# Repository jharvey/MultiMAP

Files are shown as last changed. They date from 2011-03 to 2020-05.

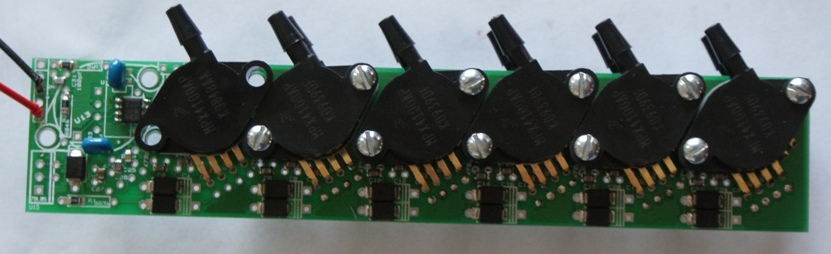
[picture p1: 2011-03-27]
pictures/2010-05-29 001.JPG

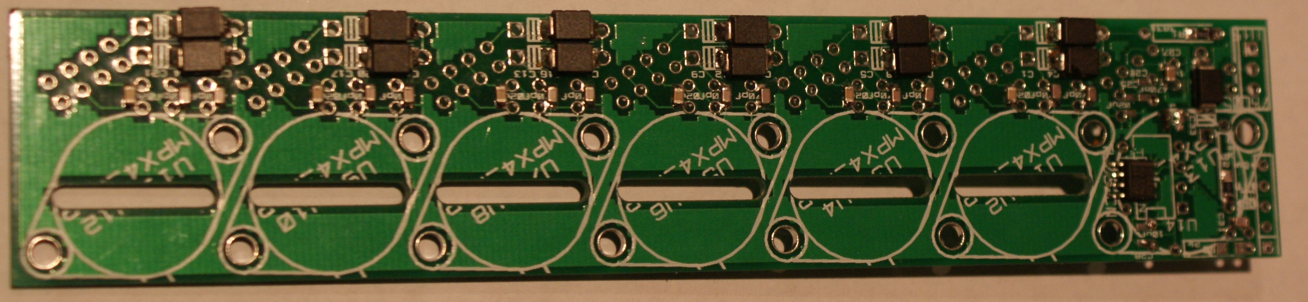
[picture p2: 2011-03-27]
pictures/other/2010-04-24 001.JPG

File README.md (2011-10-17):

### MultiMAP

This is a circuit board that would most typically be used for automotive engines running ITB setups. This board will combine multiple MAP signals, and report the lowest MAP signal to the engine control computer. This project includes designs for 2,4,6,8 and 12 MAP signals. 

This project includes, Gerber MFG files that can be uploaded to almost any MFG house, such that PCB's can be obtained. It includes BOM's and simulation files, as well as the KICAD PCB layout files. 

I have also uploaded files to BatchPCB, such that if someone want's the board, they can simply go there and purchase it.

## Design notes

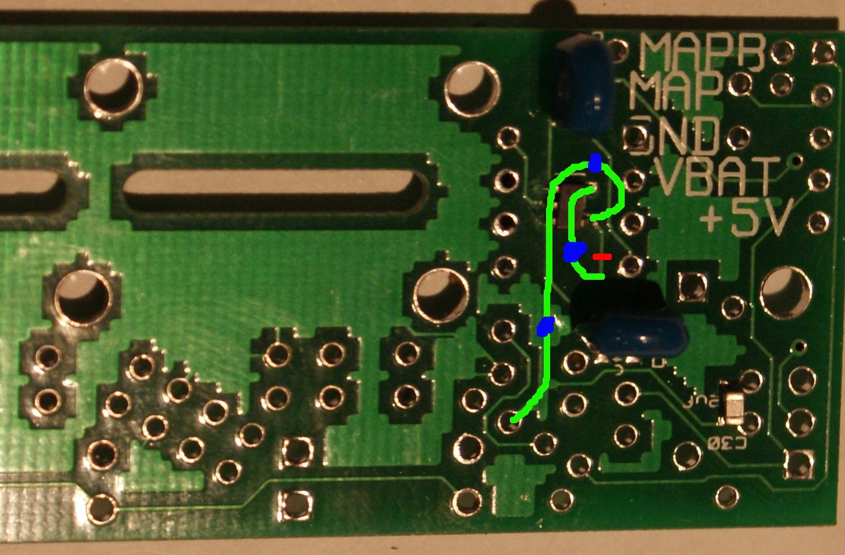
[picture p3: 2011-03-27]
pictures/other/back_mod.JPG

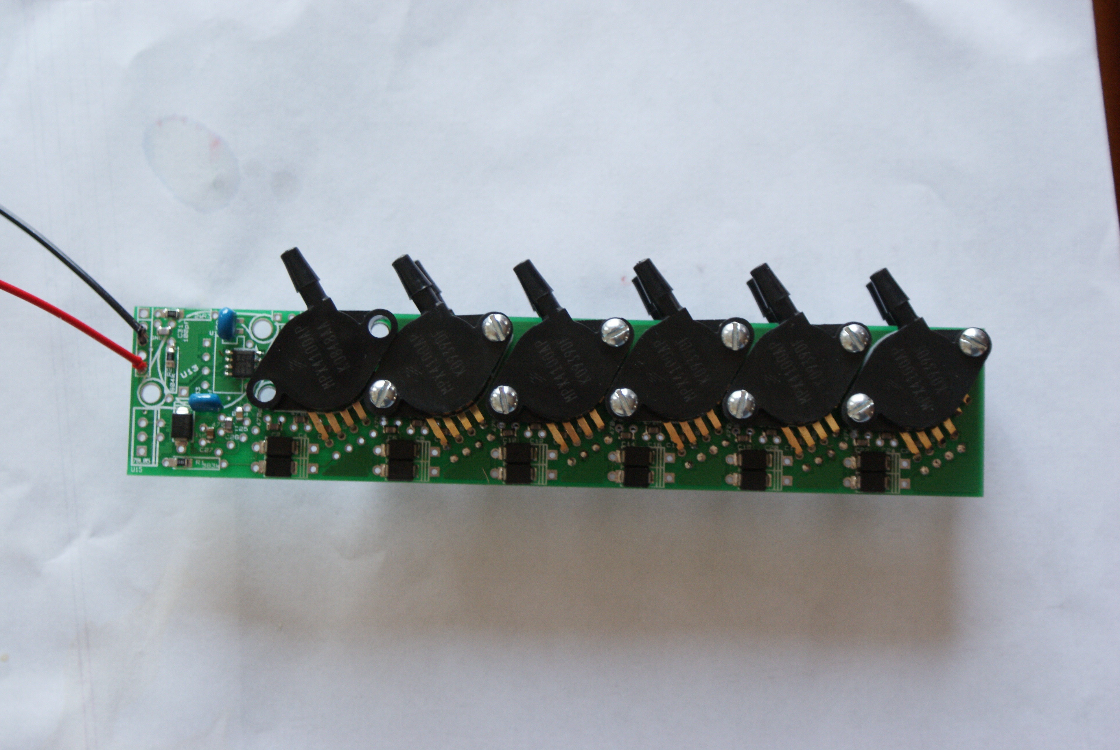
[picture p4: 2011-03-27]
pictures/2010-05-29 001small.JPG

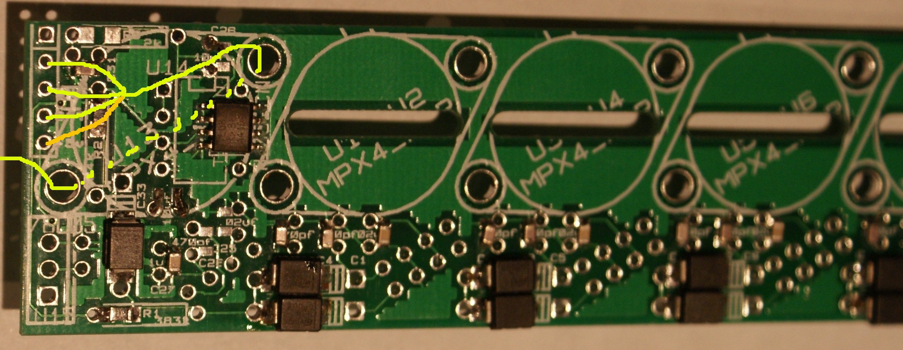
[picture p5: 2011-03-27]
pictures/other/wire_strain-relief.JPG

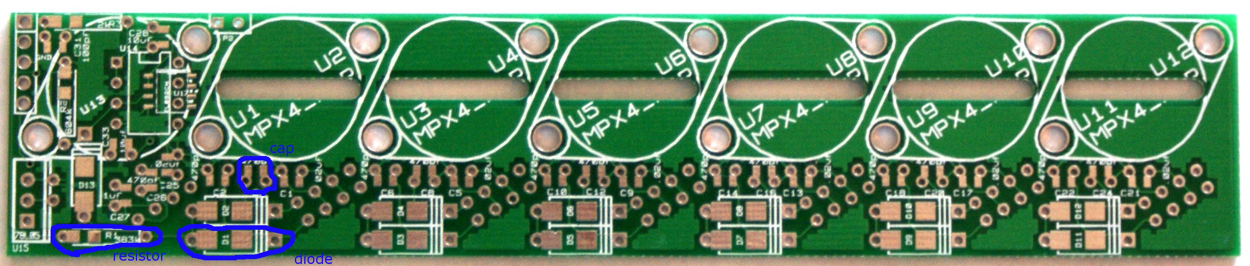
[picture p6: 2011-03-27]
pictures/other/footprints-modules.JPG

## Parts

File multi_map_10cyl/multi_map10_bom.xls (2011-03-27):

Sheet: processed_data
ref | value | MFG |  | Vendor 1 |  | Vendor 2 | # | $
C31 | 100pf | avx | 08055A101JAT2A | quest | 08055A101JAT2A | mouser | 581-08055A101J | $0.110 | These parts are always required, and this list shows surface mount devices only.
C1 | .02uf | avx | 08055C202KAT2A | quest | 08055C202KAT2A | mouser | 581-08055C202K | $0.130
C5 | .02uf | avx | 08055C202KAT2A | quest | 08055C202KAT2A | mouser | 581-08055C202K | $0.130
C9 | .02uf | avx | 08055C202KAT2A | quest | 08055C202KAT2A | mouser | 581-08055C202K | $0.130
C13 | .02uf | avx | 08055C202KAT2A | quest | 08055C202KAT2A | mouser | 581-08055C202K | $0.130
C17 | .02uf | avx | 08055C202KAT2A | quest | 08055C202KAT2A | mouser | 581-08055C202K | $0.130
C30 | 22uf | avx | 08056D226MAT2A | quest | 08056D226MAT2A | mouser | 581-08056D226M | $1.000
R3 | 2k | Vishay | CRCW08052K00FKTA | quest | CRCW08052K00FKTA | mouser | 71-CRCW08052001FT | $0.050
R1 | 383k | Vishay | CRCW0805383KFKTA | quest | CRCW0805383KFKTA | mouser | 71-CRCW0805-383K | $0.040
R2 | 604k | vishay | CRCW0805604KFKTA | quest | CRCW0805604KFKTA | mouser | 71-CRCW0805-604K-E3 | $0.050
D1 | DIODE | stmicro | STPS340U | quest | STPS340U | mouser | 511-STPS340U | $0.524
D2 | DIODE | stmicro | STPS340U | quest | STPS340U | mouser | 511-STPS340U | $0.524
D3 | DIODE | stmicro | STPS340U | quest | STPS340U | mouser | 511-STPS340U | $0.524
D4 | DIODE | stmicro | STPS340U | quest | STPS340U | mouser | 511-STPS340U | $0.524
D5 | DIODE | stmicro | STPS340U | quest | STPS340U | mouser | 511-STPS340U | $0.524
D6 | DIODE | stmicro | STPS340U | quest | STPS340U | mouser | 511-STPS340U | $0.524
D7 | DIODE | stmicro | STPS340U | quest | STPS340U | mouser | 511-STPS340U | $0.524
D8 | DIODE | stmicro | STPS340U | quest | STPS340U | mouser | 511-STPS340U | $0.524
D9 | DIODE | stmicro | STPS340U | quest | STPS340U | mouser | 511-STPS340U | $0.524
D10 | DIODE | stmicro | STPS340U | quest | STPS340U | mouser | 511-STPS340U | $0.524
D13 | DIODE | stmicro | STPS340U | quest | STPS340U | mouser | 511-STPS340U | $0.524
U14 | TL082CN | TI | TL082IDR | quest | TL082IDR | mouser | 595-TL082QDRQ1 | $0.760
C2 | 470pf | Vishay | VJ0805A471JXAAT | quest | VJ0805A471JXAAT | mouser | 581-08051A471J | $0.150
C4 | 470pf | Vishay | VJ0805A471JXAAT | quest | VJ0805A471JXAAT | mouser | 581-08051A471J | $0.150
C6 | 470pf | Vishay | VJ0805A471JXAAT | quest | VJ0805A471JXAAT | mouser | 581-08051A471J | $0.150
C8 | 470pf | Vishay | VJ0805A471JXAAT | quest | VJ0805A471JXAAT | mouser | 581-08051A471J | $0.150
C10 | 470pf | Vishay | VJ0805A471JXAAT | quest | VJ0805A471JXAAT | mouser | 581-08051A471J | $0.150
C12 | 470pf | Vishay | VJ0805A471JXAAT | quest | VJ0805A471JXAAT | mouser | 581-08051A471J | $0.150
C14 | 470pf | Vishay | VJ0805A471JXAAT | quest | VJ0805A471JXAAT | mouser | 581-08051A471J | $0.150
C16 | 470pf | Vishay | VJ0805A471JXAAT | quest | VJ0805A471JXAAT | mouser | 581-08051A471J | $0.150
C18 | 470pf | Vishay | VJ0805A471JXAAT | quest | VJ0805A471JXAAT | mouser | 581-08051A471J | $0.150
C20 | 470pf | Vishay | VJ0805A471JXAAT | quest | VJ0805A471JXAAT | mouser | 581-08051A471J | $0.150
 | PCB |  |  | Batch PCB |  |  |  | $27.190
U1 | MPX4_MAP | freescale | MPX4100AP | digikey | MPX4100AP-ND | mouser | 841-MPX4100AP1 | $11.970 | This is the non boosted MAP sensor, If your system is boosted, change to the MPX4???
U2 | MPX4_MAP | freescale | MPX4100AP | digikey | MPX4100AP-ND | mouser | 841-MPX4100AP5 | $11.970
U3 | MPX4_MAP | freescale | MPX4100AP | digikey | MPX4100AP-ND | mouser | 841-MPX4100AP6 | $11.970
U4 | MPX4_MAP | freescale | MPX4100AP | digikey | MPX4100AP-ND | mouser | 841-MPX4100AP7 | $11.970
U5 | MPX4_MAP | freescale | MPX4100AP | digikey | MPX4100AP-ND | mouser | 841-MPX4100AP8 | $11.970
U6 | MPX4_MAP | freescale | MPX4100AP | digikey | MPX4100AP-ND | mouser | 841-MPX4100AP9 | $11.970
U7 | MPX4_MAP | freescale | MPX4100AP | digikey | MPX4100AP-ND | mouser | 841-MPX4100AP10 | $11.970
U8 | MPX4_MAP | freescale | MPX4100AP | digikey | MPX4100AP-ND | mouser | 841-MPX4100AP11 | $11.970
U9 | MPX4_MAP | freescale | MPX4100AP | digikey | MPX4100AP-ND | mouser | 841-MPX4100AP12 | $11.970
U10 | MPX4_MAP | freescale | MPX4100AP | digikey | MPX4100AP-ND | mouser | 841-MPX4100AP2 | $11.970
C27 | 1uf | avx | 08053D105KAT2A | quest | 08053D105KAT2A | mouser | 581-08053D105K | $0.660 | If you choose to provide 12V to the baord instead of 5V, added these parts.
U15 | 78L05 | on-semi | MC7805ACTG | newark | 45J1442 |  |  |  | Most ECU MAP's will provide 5V instead of 12V.
U16 | MAX1682 | Maxim | MAX1682EUK-T | summit | MAX1682EUK+T |  |  |  | Most setups will need the onboard 10v generator, to include this option, add these parts
C28 | 10uf | avx | 08052G106ZAT2A | quest | 08052G106ZAT2A |  |  | $0.130 | (supplying 12V still requires these parts if the 10V generation is desired)
C33 | 10uf | avx | 08052G106ZAT2A | quest | 08052G106ZAT2A |  |  | $0.130
 |  |  |  |  |  |  |  |  | If you decide to go without the onbaord 10V generator, do not include C28, C33 or U16, instead
 |  |  |  |  |  |  |  |  | add a jumper wire in the P2 socket and change R1 and R2 to these resistors.
 |  |  |  |  |  |  |  |  | The below parts are not typically populated
U13 | MPX4_MAP |  |  |  |  |  |  |  | U13 is for barametric correct, which isn't needed with the above suggested MAP sensor.
C29 | #NAME? |  |  |  |  |  |  |  | C29 and C32 allow some adjustment to the 10V generator if required.
C32 | #NAME?
P1 | CONN_5 |  |  |  |  |  |  |  | This is the connector where the wires are soldered to this board,
U? | TL082CN |  |  |  |  |  |  |  | This is the second foot print for the opamp. It allows both SMT and thru hole components.
 |  |  |  |  |  |  | total cost | $157.73

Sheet: multi_map_raw_data
ref | value | sheet number | sheet name | footprint | Field1 | Field2
C1 | .02uf | SM0805-C1 | avx | 08055C202KAT2A | quest | 08055C202KAT2A
C10 | 470pf | SM0805-C1 | Vishay | VJ0805A471JXAAT | quest | VJ0805A471JXAAT
C12 | 470pf | SM0805-C1 | Vishay | VJ0805A471JXAAT | quest | VJ0805A471JXAAT
C13 | .02uf | SM0805-C1 | avx | 08055C202KAT2A | quest | 08055C202KAT2A
C14 | 470pf | SM0805-C1 | Vishay | VJ0805A471JXAAT | quest | VJ0805A471JXAAT
C16 | 470pf | SM0805-C1 | Vishay | VJ0805A471JXAAT | quest | VJ0805A471JXAAT
C17 | .02uf | SM0805-C1 | avx | 08055C202KAT2A | quest | 08055C202KAT2A
C18 | 470pf | SM0805-C1 | Vishay | VJ0805A471JXAAT | quest | VJ0805A471JXAAT
C2 | 470pf | SM0805-C1 | Vishay | VJ0805A471JXAAT | quest | VJ0805A471JXAAT
C20 | 470pf | SM0805-C1 | Vishay | VJ0805A471JXAAT | quest | VJ0805A471JXAAT
C21 | .02uf | SM0805-C1 | avx | 08055C202KAT2A | quest | 08055C202KAT2A
C22 | 470pf | SM0805-C1 | Vishay | VJ0805A471JXAAT | quest | VJ0805A471JXAAT
C24 | 470pf | SM0805-C1 | Vishay | VJ0805A471JXAAT | quest | VJ0805A471JXAAT
C25 | .02uf | SM0805-C1 | avx | 08055C202KAT2A | quest | 08055C202KAT2A
C26 | 470pf | SM0805-C1 | Vishay | VJ0805A471JXAAT | quest | VJ0805A471JXAAT
C27 | 1uf | SM0805-C1 | avx | 08053D105KAT2A | quest | 08053D105KAT2A
C28 | 10uf | SM0805-C1 | mutara | GRM40C0G202J050AL | quest | GRM40C0G202J050AL
C29 | #NAME? | SM0805-C1
C30 | 22uf | SM0805-C1 | avx | 08056D226MAT2A | quest | 08056D226MAT2A
C31 | 100pf | SM0805-C1 | avx | 08055A101JAT2A | quest | 08055A101JAT2A
C32 | #NAME? | SM0805-C1
C33 | 10uf | SM0805-C1 | mutara | GRM40C0G202J050AL | quest | GRM40C0G202J050AL
C4 | 470pf | SM0805-C1 | Vishay | VJ0805A471JXAAT | quest | VJ0805A471JXAAT
C5 | .02uf | SM0805-C1 | avx | 08055C202KAT2A | quest | 08055C202KAT2A
C6 | 470pf | SM0805-C1 | Vishay | VJ0805A471JXAAT | quest | VJ0805A471JXAAT
C8 | 470pf | SM0805-C1 | Vishay | VJ0805A471JXAAT | quest | VJ0805A471JXAAT
C9 | .02uf | SM0805-C1 | avx | 08055C202KAT2A | quest | 08055C202KAT2A
D1 | DIODE | D4-SMB | stmicro | STPS340U | quest | STPS340U
D10 | DIODE | D4-SMB | stmicro | STPS340U | quest | STPS340U
D11 | DIODE | D4-SMB | stmicro | STPS340U | quest | STPS340U
D12 | DIODE | D4-SMB | stmicro | STPS340U | quest | STPS340U
D13 | DIODE | D4-SMB | stmicro | STPS340U | quest | STPS340U
D2 | DIODE | D4-SMB | stmicro | STPS340U | quest | STPS340U
D3 | DIODE | D4-SMB | stmicro | STPS340U | quest | STPS340U
D4 | DIODE | D4-SMB | stmicro | STPS340U | quest | STPS340U
D5 | DIODE | D4-SMB | stmicro | STPS340U | quest | STPS340U
D6 | DIODE | D4-SMB | stmicro | STPS340U | quest | STPS340U
D7 | DIODE | D4-SMB | stmicro | STPS340U | quest | STPS340U
D8 | DIODE | D4-SMB | stmicro | STPS340U | quest | STPS340U
D9 | DIODE | D4-SMB | stmicro | STPS340U | quest | STPS340U
P1 | CONN_5 | SIL-5
R1 | 383k | R4-SM0805 | Vishay | CRCW0805383KFKTA | quest | CRCW0805383KFKTA
R2 | 604k | R4-SM0805 | vishay | CRCW0805604KFKTA | quest | CRCW0805604KFKTA
R3 | 2k | R4-SM0805 | Vishay | CRCW0805100RFKEA | quest | CRCW0805100RFKEA
U1 | MPX4_MAP | MPX-4_MAP_2
U10 | MPX4_MAP | MPX-4_MAP
U11 | MPX4_MAP | MPX-4_MAP_2
U12 | MPX4_MAP | MPX-4_MAP
U13 | MPX4_MAP | MPX-4_MAP_2
U14 | TL082CN | 8DIP300 | TI | TL082IDR | quest | TL082IDR
U15 | 78L05 | TO220_VERT | on-semi | MC7805ACTG | newark | 45J1442
U16 | MAX1682 | SOT23-5 | Maxim | MAX1682EUK-T | summit | MAX1682EUK+T
U2 | MPX4_MAP | MPX-4_MAP
U3 | MPX4_MAP | MPX-4_MAP_2
U4 | MPX4_MAP | MPX-4_MAP
U5 | MPX4_MAP | MPX-4_MAP_2
U6 | MPX4_MAP | MPX-4_MAP
U7 | MPX4_MAP | MPX-4_MAP_2
U8 | MPX4_MAP | MPX-4_MAP
U9 | MPX4_MAP | MPX-4_MAP_2
U? | TL082CN | SO8E

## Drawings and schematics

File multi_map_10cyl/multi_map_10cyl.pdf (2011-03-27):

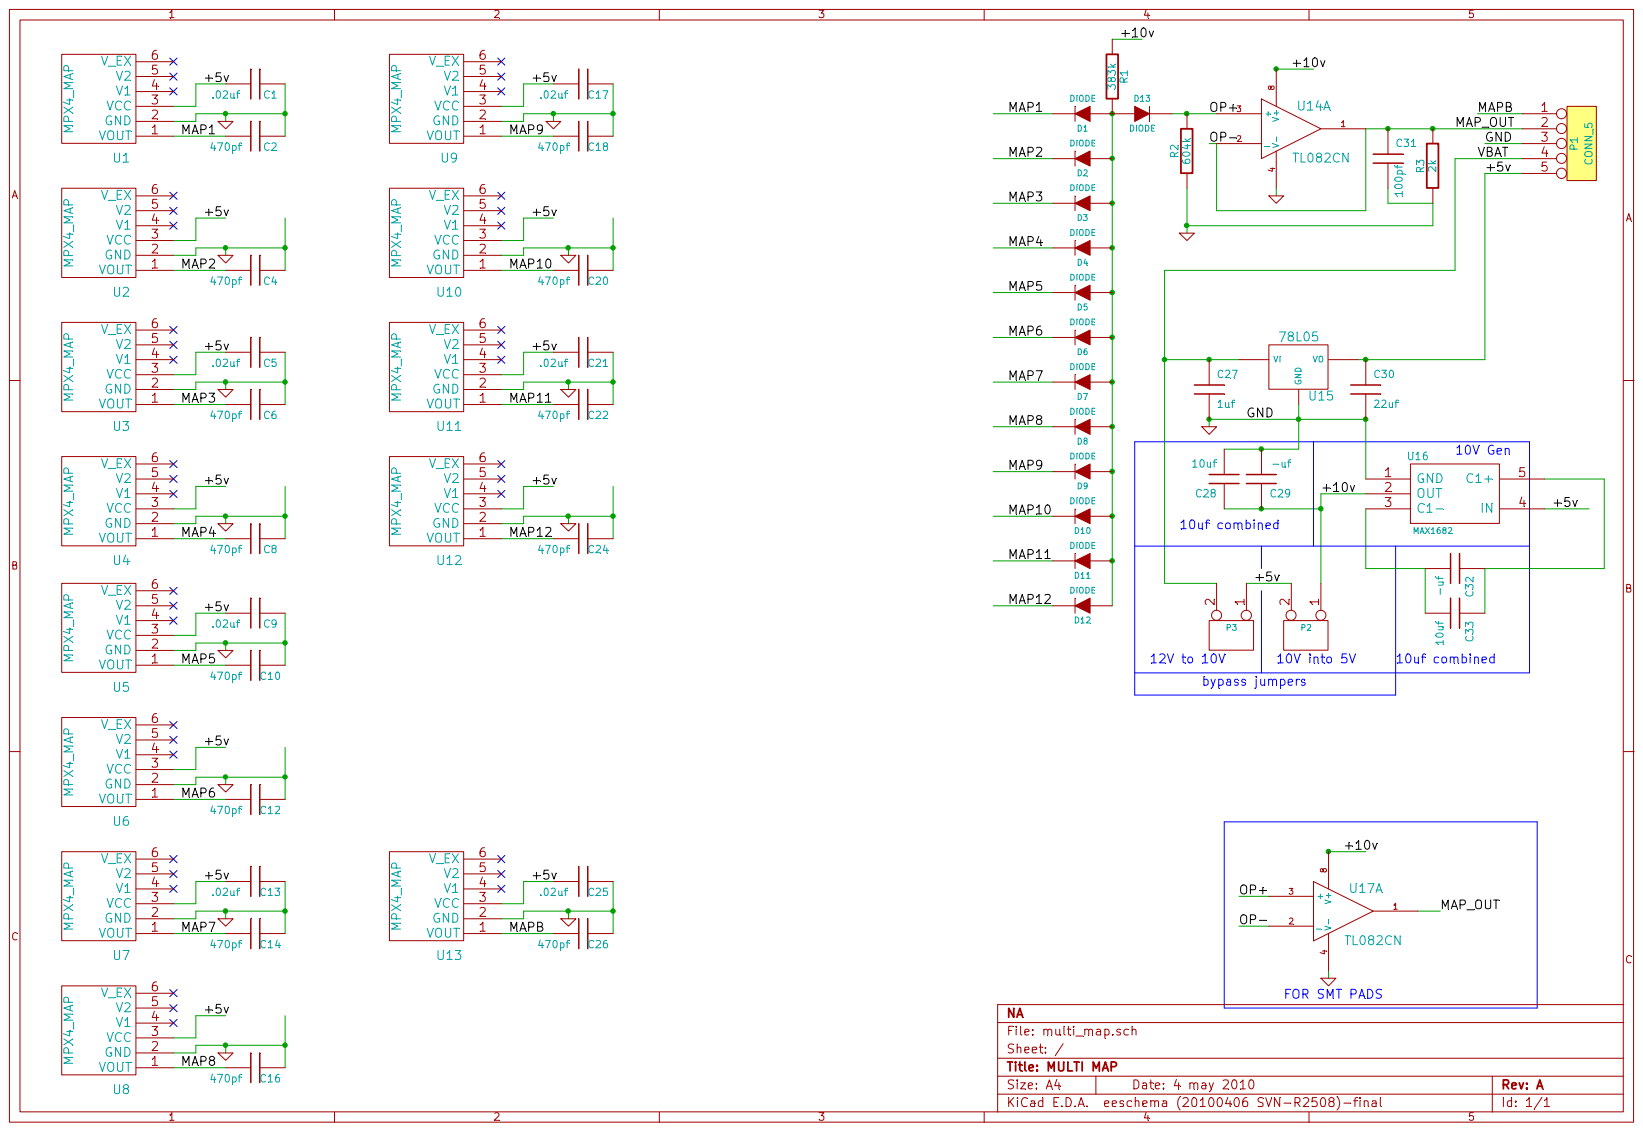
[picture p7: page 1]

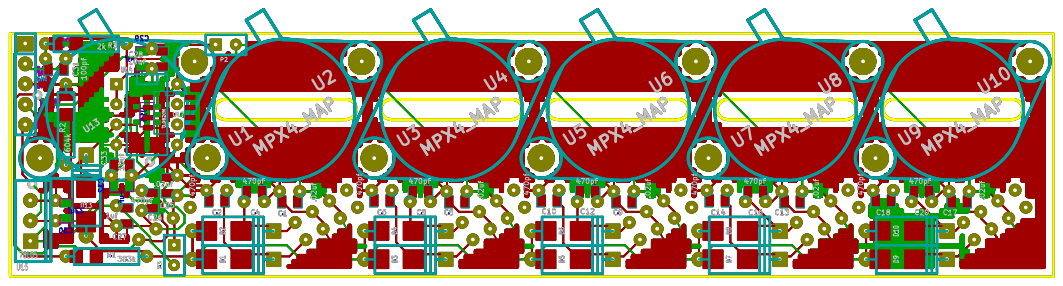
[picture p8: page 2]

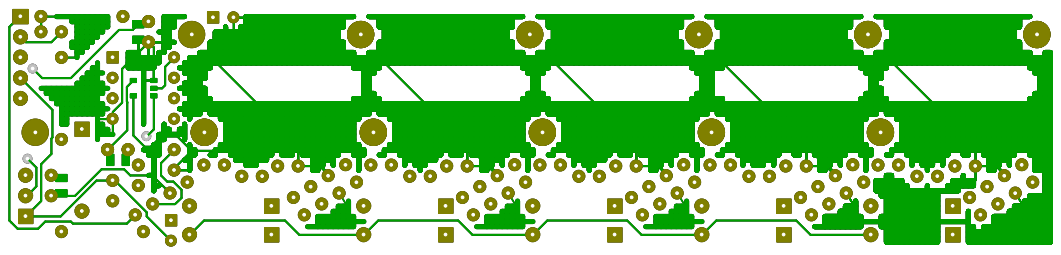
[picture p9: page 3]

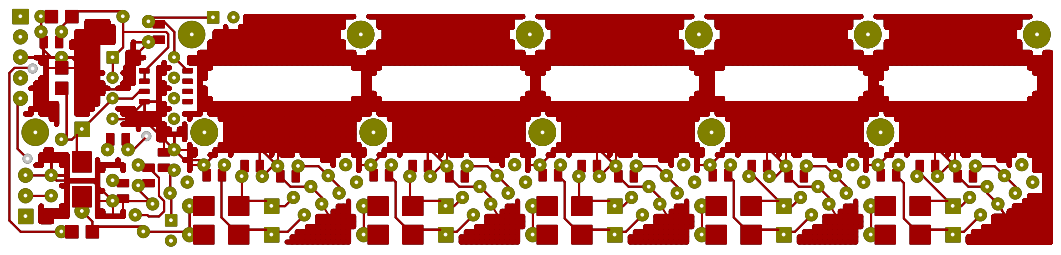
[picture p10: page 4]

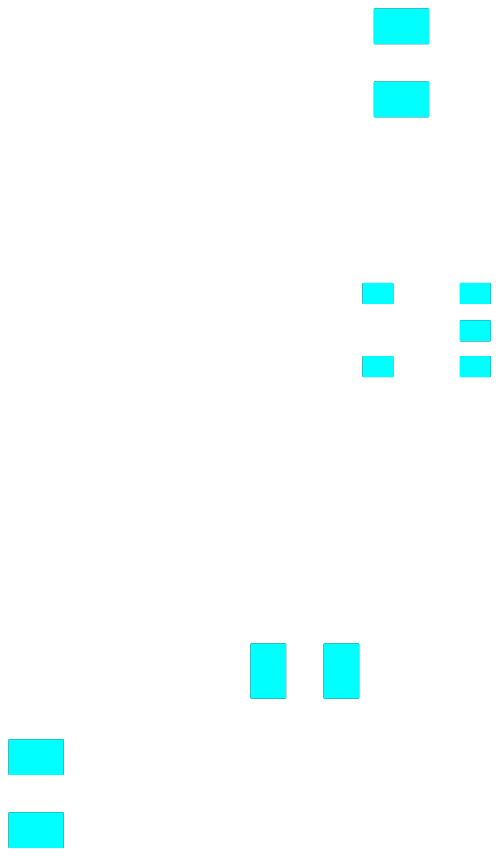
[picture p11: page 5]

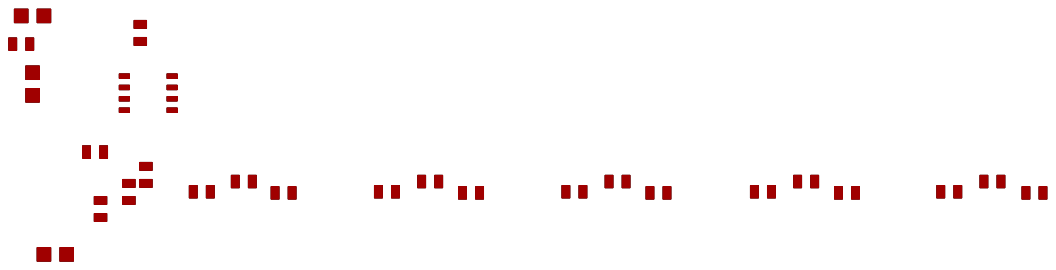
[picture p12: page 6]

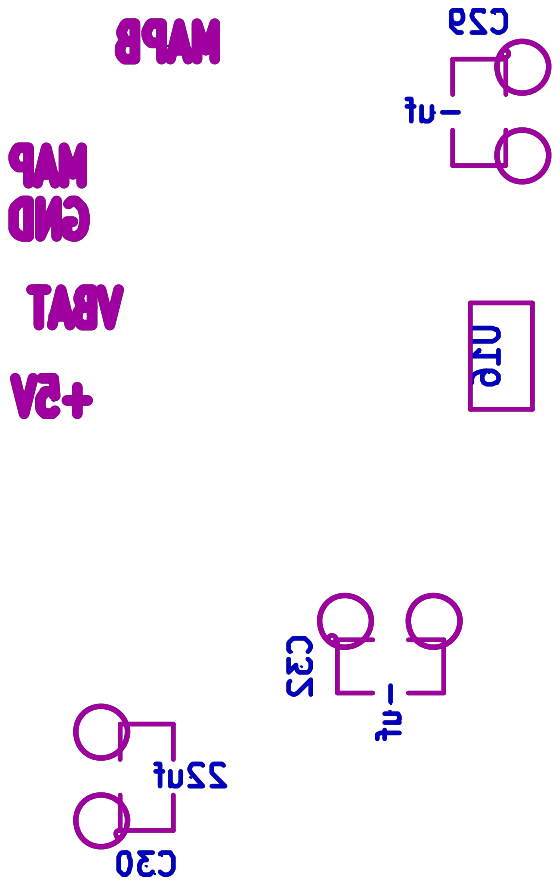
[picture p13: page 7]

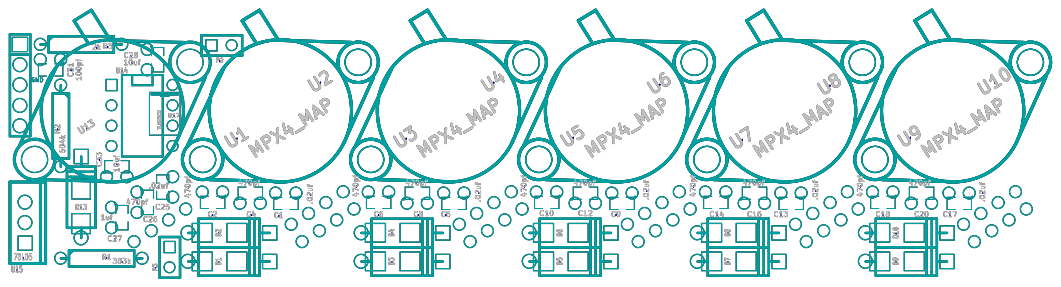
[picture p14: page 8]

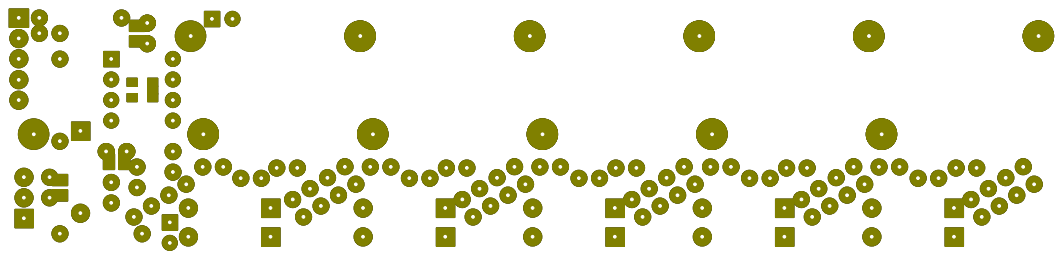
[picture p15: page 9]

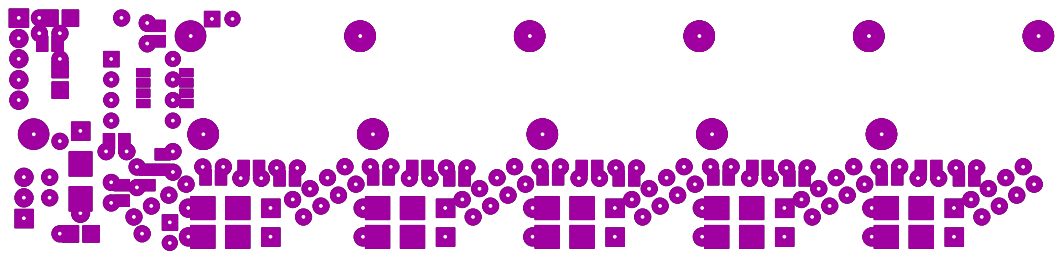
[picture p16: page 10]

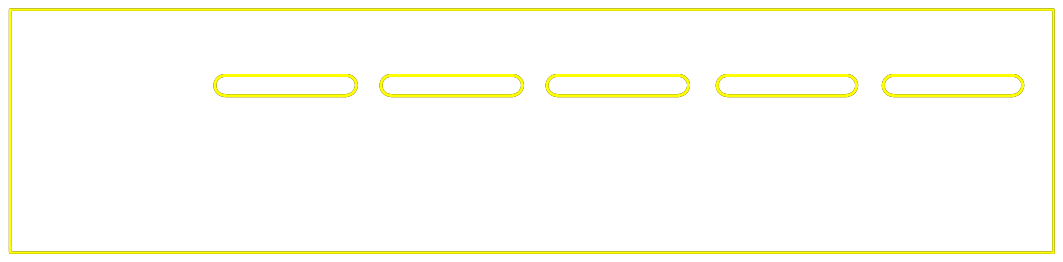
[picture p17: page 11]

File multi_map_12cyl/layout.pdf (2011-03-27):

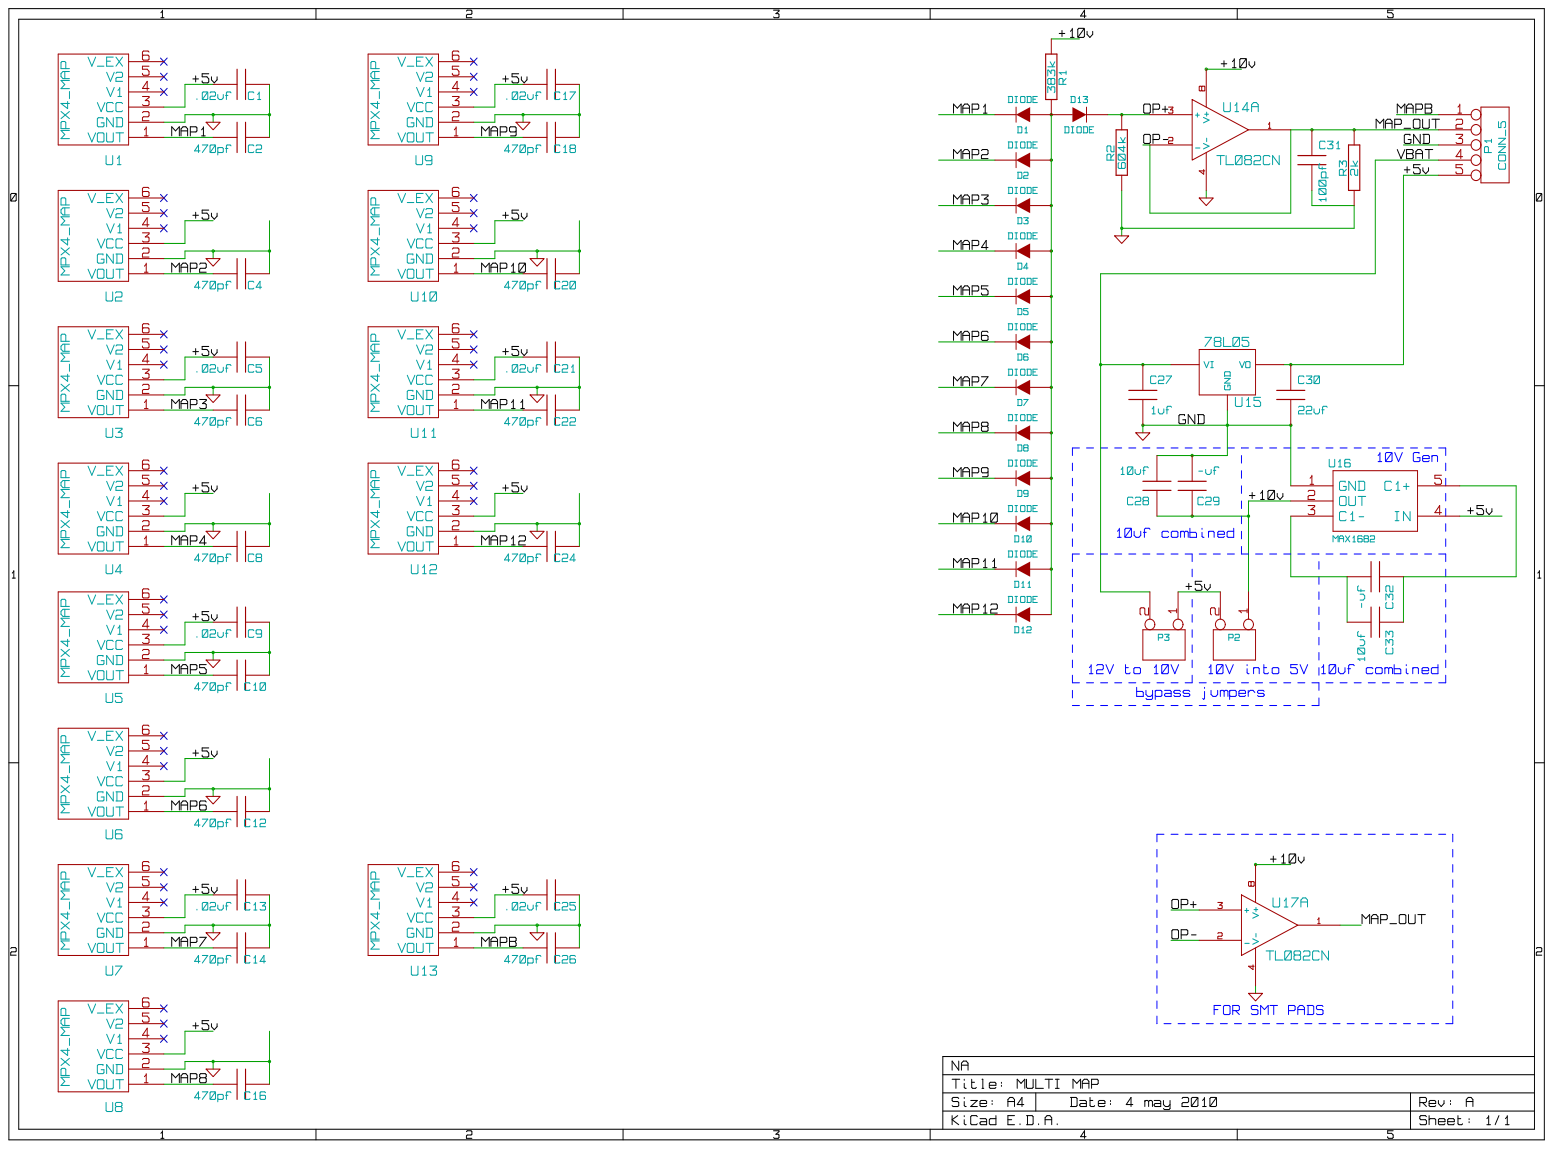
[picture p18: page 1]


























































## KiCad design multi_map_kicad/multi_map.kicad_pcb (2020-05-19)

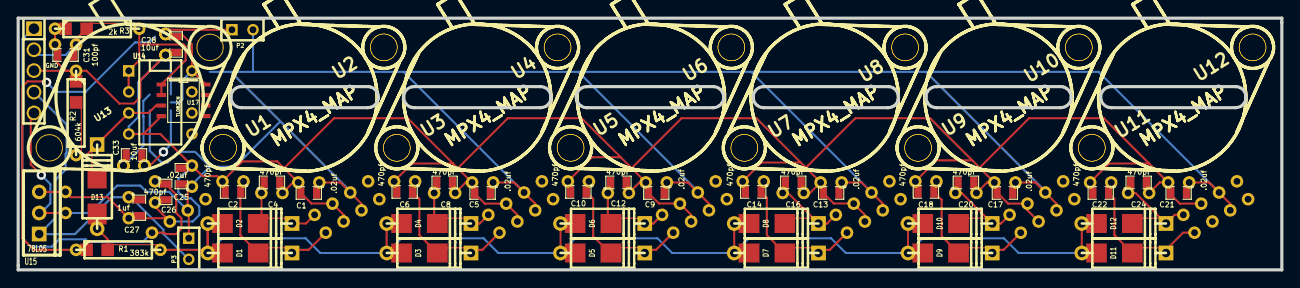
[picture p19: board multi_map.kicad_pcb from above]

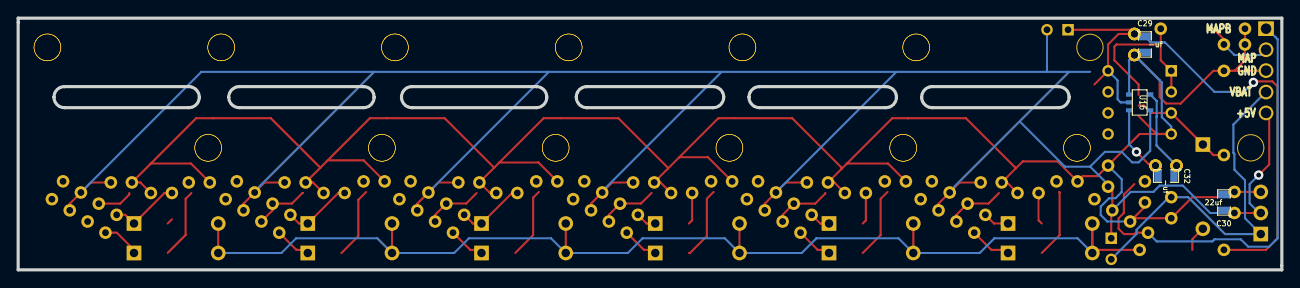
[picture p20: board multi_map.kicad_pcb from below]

Board: 2 copper layers, 152.4 x 30.4 mm, 63 parts (4 on the bottom side), 22 nets.

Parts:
C1, C5, C9, C13, C17, C21, C25: .02uf; SM0805-C1
C2, C4, C6, C8, C10, C12, C14, C16, C18, C20, C22, C24, C26: 470pf; SM0805-C1
C27: 1uf; SM0805-C1
C28, C33: 10uf; SM0805-C1
C29, C32: -uf; SM0805-C1
C30: 22uf; SM0805-C1
C31: 100pf; SM0805-C1
D1, D2, D3, D4, D5, D6, D7, D8, D9, D10, D11, D12, D13: DIODE; D4-SMB
P1: CONN_5; SIL-5
P2, P3: CONN_2; SIL-2
R1: 383k; R4-SM0805
R2: 604k; R4-SM0805
R3: 2k; R4-SM0805
U1, U3, U5, U7, U9, U11, U13: MPX4_MAP; MPX-4_MAP_2
U2, U4, U6, U8, U10, U12: MPX4_MAP; MPX-4_MAP
U14: TL082CN; 8dip300
U15: 78L05; TO220_VERT
U16: MAX1682; SOT23-5
U17: TL082CN; SO8E

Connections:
+5v_1: C1.1, C5.1, C9.1, C13.1, C17.1, C21.1, C25.1, C30.1, P1.5, P2.2, P3.1, U1.3, U2.3, U3.3, U4.3, U5.3, U6.3, U7.3, U8.3, U9.3, U10.3, U11.3, U12.3, U13.3, U15.3, U16.4
+10v_1: C28.1, C29.1, P2.1, R1.1, U14.8, U16.2, U17.8
GND: C1.2, C2.2, C4.2, C5.2, C6.2, C8.2, C9.2, C10.2, C12.2, C13.2, C14.2, C16.2, C17.2, C18.2, C20.2, C21.2, C22.2, C24.2, C25.2, C26.2, C27.2, C28.2, C29.2, C30.2, C31.2, P1.3, R2.1, R3.1, U1.2, U2.2, U3.2, U4.2, U5.2, U6.2, U7.2, U8.2, U9.2, U10.2, U11.2, U12.2, U13.2, U14.4, U15.2, U16.1, U17.4
MAP1_1: C2.1, D1.2, U1.1
MAP2_1: C4.1, D2.2, U2.1
MAP3_1: C6.1, D3.2, U3.1
MAP4_1: C8.1, D4.2, U4.1
MAP5_1: C10.1, D5.2, U5.1
MAP6_1: C12.1, D6.2, U6.1
MAP7_1: C14.1, D7.2, U7.1
MAP8_1: C16.1, D8.2, U8.1
MAP9_1: C18.1, D9.2, U9.1
MAP10_1: C20.1, D10.2, U10.1
MAP11_1: C22.1, D11.2, U11.1
MAP12_1: C24.1, D12.2, U12.1
MAPB_1: C26.1, P1.1, U13.1
unnamed: C32.1, C33.1, U16.5
unnamed: C32.2, C33.2, U16.3
unnamed: D1.1, D2.1, D3.1, D4.1, D5.1, D6.1, D7.1, D8.1, D9.1, D10.1, D11.1, D12.1, D13.1, R1.2
OP+_1: D13.2, R2.2, U14.3, U17.3
OP-_1: C31.1, P1.2, R3.2, U14.1, U14.2, U17.1, U17.2
VBAT_1: C27.1, P1.4, P3.2, U15.1

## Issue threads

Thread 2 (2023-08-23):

Has this board ever been used on a 4 cylinder?

AlessandroEmm, 2023-08-23:
Hey there

I know a bit a late comer to the topic. I've been looking mostly at multimaps with a MCUs doing the search for the lowest voltage. This is the first and only discrete example i've found. May I ask whether it was used already on 4cylinders?

Thanks!
Alessandro

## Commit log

2011-03-27 moved to git hub from google code
    [$savepcb.brd, MULTI_MAP.sch, MULTI_MAP_diode.sch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]
2020-05-19 Updated to KC4
    [multi_map.sch]
2020-05-19 Updated to KC5
    [multi_map.brd, multi_map.sch]
